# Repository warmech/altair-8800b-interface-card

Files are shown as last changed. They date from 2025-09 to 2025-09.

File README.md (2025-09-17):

# Altair 8800B Interface Card
This is a reproduction of the MITS Altair 8800B Interface card, with some cleanup to trace routing and pad placement and an additional quality of life improvement. This card serves as the interface between the Display/Control board and the rest of the 8800B.

This card originally used a staggered ribbon cable terminator that is both expensive and difficult to crimp unless you have the right tools. This version includes a set of two alternative 2x17, 0.1” headers to allow you to use a ribbon cable with female IDC on one end and card-edge on the other. If you cannot locate a pre-fabricated 34-pin cable with these terminators, inexpensive crimping tools are easily found at online retailers that will allow you to build your own cable. The original staggered terminator is crimped and soldered directly to the card PCB and this presented some issues. First, while these are available for sale at retailers such as Mouser and DigiKey, they are around $5.00 per connector (whereas nice, keyed male IDC connectors can be had for a fraction of that), they are not usually stocked in large quantities and may be back-ordered by the time you are assembling this card. Second, these staggered connectors have no stress relief and flexing/bending of the ribbon cables over time will cause the connector to loosen to the extent that signal transmission issues may arise between the interface card and the D/C board. In the case of my and others’ Altairs, this issue caused bus issues that were extremely difficult to hunt down and resolve. Last, if you are assembling your own cables, the staggered connectors require a special insert to crimp; these inserts are neither easy to find nor cheap, so an alternative IDC header offers an inexpensive alternative.

This design is presently untested and I am awaiting a set to be fabricated. Once I have tested this adapter in my 8800B, I will update this disclaimer to indicate as much. Until this disclaimer is updated and/or removed, this PCB is to be strictly treated as experimental only. User beware – these project and fabrication files are provided with absolutely zero guarantees.

For the accompanying CPU, Interface, and Display/Control boards, please see the following repositories:

[Altair 8800B CPU Card](https://github.com/warmech/altair-8800b-cpu-card)

[Altair 8800B Display/Control PCB](https://github.com/warmech/altair-8800b-display-control-pcb)

[Altair 8800B 1702-to-2716/2732 Adapter](https://github.com/warmech/altair-8800b-1702-to-2716-eprom-adapter)

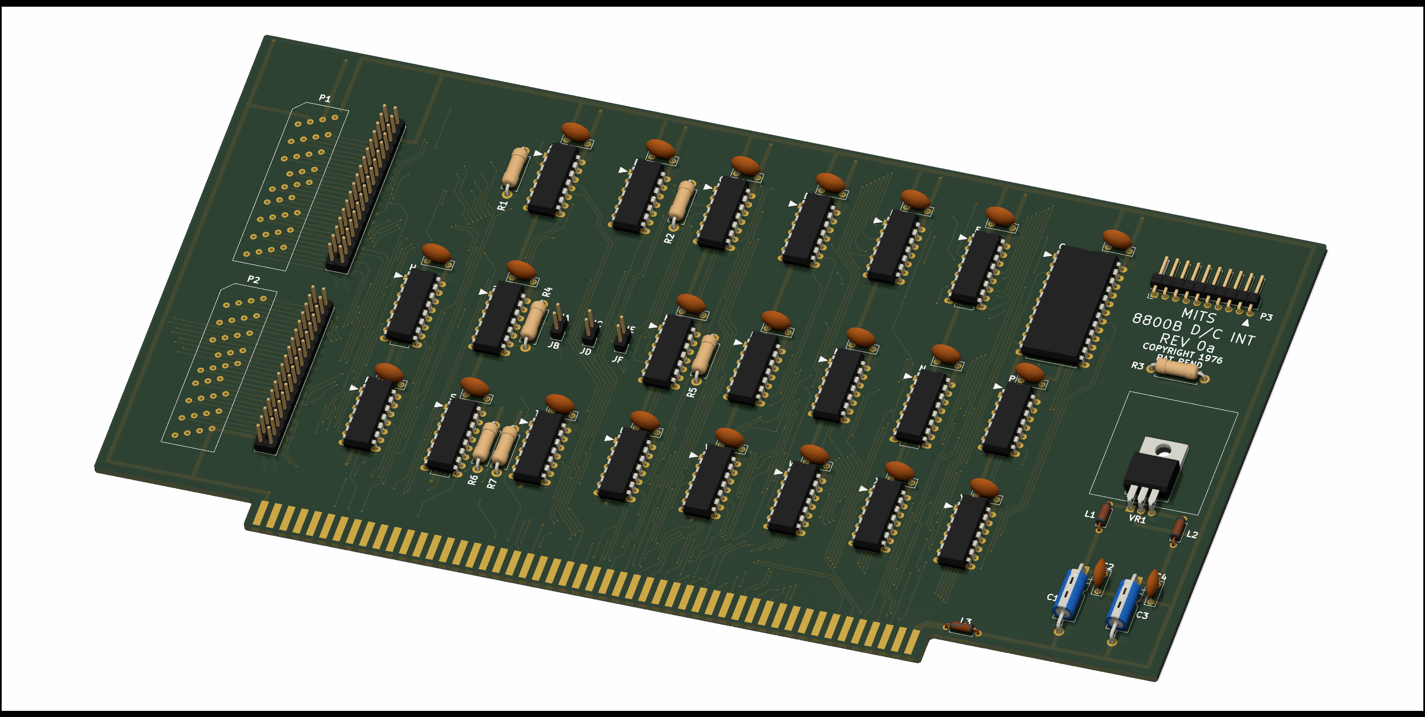
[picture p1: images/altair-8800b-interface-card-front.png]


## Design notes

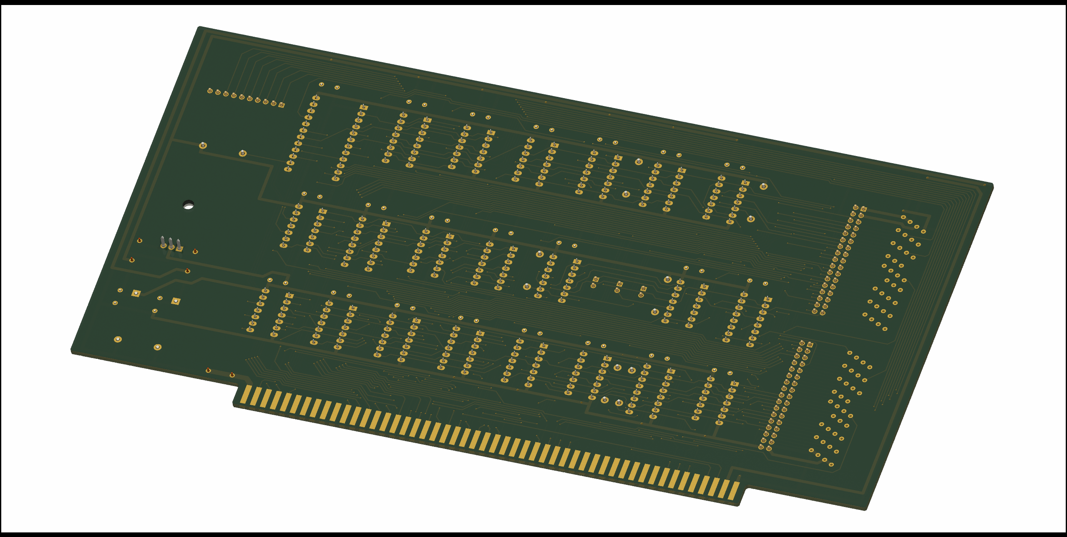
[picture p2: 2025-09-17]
images/altair-8800b-interface-card-rear.png

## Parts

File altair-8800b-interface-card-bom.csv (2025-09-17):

Source:
Date: | 9/17/2025 0:42
Tool: | Eeschema 7.0.11-rc3
Generator:
Component Count: | 68
Collated Components:
Item | Qty | Reference(s) | Value | LibPart | Footprint | Datasheet | DNP
1 | 2 | C1, C3 | 33uF / 16V | Device:C_Polarized_US | Capacitor_THT:CP_Axial_L11.0mm_D5.0mm_P18.00mm_Horizontal | ~
2 | 2 | C2, C4 | 0.1uF / 16V | Device:C | Capacitor_THT_Custom:C_Disc_D7.0mm_W2.3mm_P5.00mm | ~
3 | 22 | C5, C6, C7, C8, C9, C10, C11, C12, C13, C14, C15, C16, C17, C18, C19, C20, C21, C22, C23, C24, C25, C26 | 0.1uF / 12V | Device:C | Capacitor_THT_Custom:C_Disc_D7.0mm_W2.3mm_P5.00mm | ~
4 | 1 | JP1 | JA-JB | Jumper:Jumper_2_Open | Connector_PinHeader_2.54mm:PinHeader_1x02_P2.54mm_Vertical | ~
5 | 1 | JP2 | JC-JD | Jumper:Jumper_2_Open | Connector_PinHeader_2.54mm:PinHeader_1x02_P2.54mm_Vertical | ~
6 | 1 | JP3 | JE-JF | Jumper:Jumper_2_Open | Connector_PinHeader_2.54mm:PinHeader_1x02_P2.54mm_Vertical | ~
7 | 3 | L1, L2, L3 | L | Device:L | Inductor_THT:L_Axial_L5.3mm_D2.2mm_P7.62mm_Horizontal_Vishay_IM-1 | ~
8 | 2 | P1, P2 | ~ | Connector_Custom:Ribbon_Cable_Header_PCB_Connector_34_Pin | Connector_Custom:Ribbon_Cable_Header_PCB_Connector_34_Pin
9 | 1 | P3 | CPU Data Bus Conn | Connector_Generic:Conn_01x10 | Connector_PinHeader_2.54mm:PinHeader_1x10_P2.54mm_Horizontal | ~
10 | 1 | P4 | Altair System Bus (S-100) | Connector_Custom:MITS_Altair_Bus_CardEdge | Connector_Custom:Altair_8800_Bus_Card_Edge
11 | 2 | P5, P6 | Conn_02x17_Top_Bottom | Connector_Generic:Conn_02x17_Top_Bottom | Connector_PinHeader_2.54mm:PinHeader_2x17_P2.54mm_Vertical | ~
12 | 7 | R1, R2, R3, R4, R5, R6, R7 | 2.2K | Device:R_US | Resistor_THT:R_Axial_DIN0411_L9.9mm_D3.6mm_P12.70mm_Horizontal | ~
13 | 1 | U1 | 74LS13 (A) | 74xx:74LS13 | Package_DIP:DIP-14_W7.62mm_LongPads | http://www.ti.com/lit/gpn/sn74LS13
14 | 1 | U2 | 74LS13 (B) | 74xx:74LS13 | Package_DIP:DIP-14_W7.62mm_LongPads | http://www.ti.com/lit/gpn/sn74LS13
15 | 1 | U3 | 74LS04 (C) | 74xx:74LS04 | Package_DIP:DIP-14_W7.62mm_LongPads | http://www.ti.com/lit/gpn/sn74LS04
16 | 1 | U4 | 74LS02 (D) | 74xx:7402 | Package_DIP:DIP-14_W7.62mm_LongPads | http://www.ti.com/lit/gpn/sn7402
17 | 1 | U5 | 74LS04 (E) | 74xx:74LS04 | Package_DIP:DIP-14_W7.62mm_LongPads | http://www.ti.com/lit/gpn/sn74LS04
18 | 1 | U6 | 74LS367 (F) | :74LS367_6 | Package_DIP:DIP-16_W7.62mm_LongPads
19 | 1 | U7 | 8212 (G) | Interface_Custom:8212 | Package_DIP:DIP-24_W15.24mm_LongPads
20 | 1 | U8 | 74LS367 (H) | :74LS367_8 | Package_DIP:DIP-16_W7.62mm_LongPads
21 | 1 | U9 | 74LS00 (J) | 74xx:7400 | Package_DIP:DIP-14_W7.62mm_LongPads | http://www.ti.com/lit/gpn/sn7400
22 | 1 | U10 | 74LS10 (K) | 74xx:74LS10 | Package_DIP:DIP-14_W7.62mm_LongPads | http://www.ti.com/lit/gpn/sn74LS10
23 | 1 | U11 | 74LS13 (L) | 74xx:74LS13 | Package_DIP:DIP-14_W7.62mm_LongPads | http://www.ti.com/lit/gpn/sn74LS13
24 | 1 | U12 | 74LS04 (M) | 74xx:74LS04 | Package_DIP:DIP-14_W7.62mm_LongPads | http://www.ti.com/lit/gpn/sn74LS04
25 | 1 | U13 | 74LS367 (N) | :74LS367_20 | Package_DIP:DIP-16_W7.62mm_LongPads
26 | 1 | U14 | 74LS04 (P) | 74xx:74LS04 | Package_DIP:DIP-14_W7.62mm_LongPads | http://www.ti.com/lit/gpn/sn74LS04
27 | 1 | U16 | 74LS04 (R) | 74xx:74LS04 | Package_DIP:DIP-14_W7.62mm_LongPads | http://www.ti.com/lit/gpn/sn74LS04
28 | 1 | U17 | 74LS367 (S) | :74LS367_26 | Package_DIP:DIP-16_W7.62mm_LongPads
29 | 1 | U18 | 74LS04 (T) | 74xx:74LS04 | Package_DIP:DIP-14_W7.62mm_LongPads | http://www.ti.com/lit/gpn/sn74LS04
30 | 1 | U19 | 74LS04 (U) | 74xx:74LS04 | Package_DIP:DIP-14_W7.62mm_LongPads | http://www.ti.com/lit/gpn/sn74LS04
31 | 1 | U20 | 74LS04 (V) | 74xx:74LS04 | Package_DIP:DIP-14_W7.62mm_LongPads | http://www.ti.com/lit/gpn/sn74LS04
32 | 1 | U21 | 74LS04 (W) | 74xx:74LS04 | Package_DIP:DIP-14_W7.62mm_LongPads | http://www.ti.com/lit/gpn/sn74LS04
33 | 1 | U22 | 74LS04 (X) | 74xx:74LS04 | Package_DIP:DIP-14_W7.62mm_LongPads | http://www.ti.com/lit/gpn/sn74LS04
34 | 1 | U23 | 74LS04 (Y) | 74xx:74LS04 | Package_DIP:DIP-14_W7.62mm_LongPads | http://www.ti.com/lit/gpn/sn74LS04
35 | 1 | VR1 | 7805 | Regulator_Linear:L7805 | Package_TO_SOT_THT:TO-220-3_Horizontal_TabDown | http://www.st.com/content/ccc/resource/technical/document/datasheet/41/4f/b3/b0/12/d4/47/88/CD00000444.pdf/files/CD00000444.pdf/jcr:content/translations/en.CD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

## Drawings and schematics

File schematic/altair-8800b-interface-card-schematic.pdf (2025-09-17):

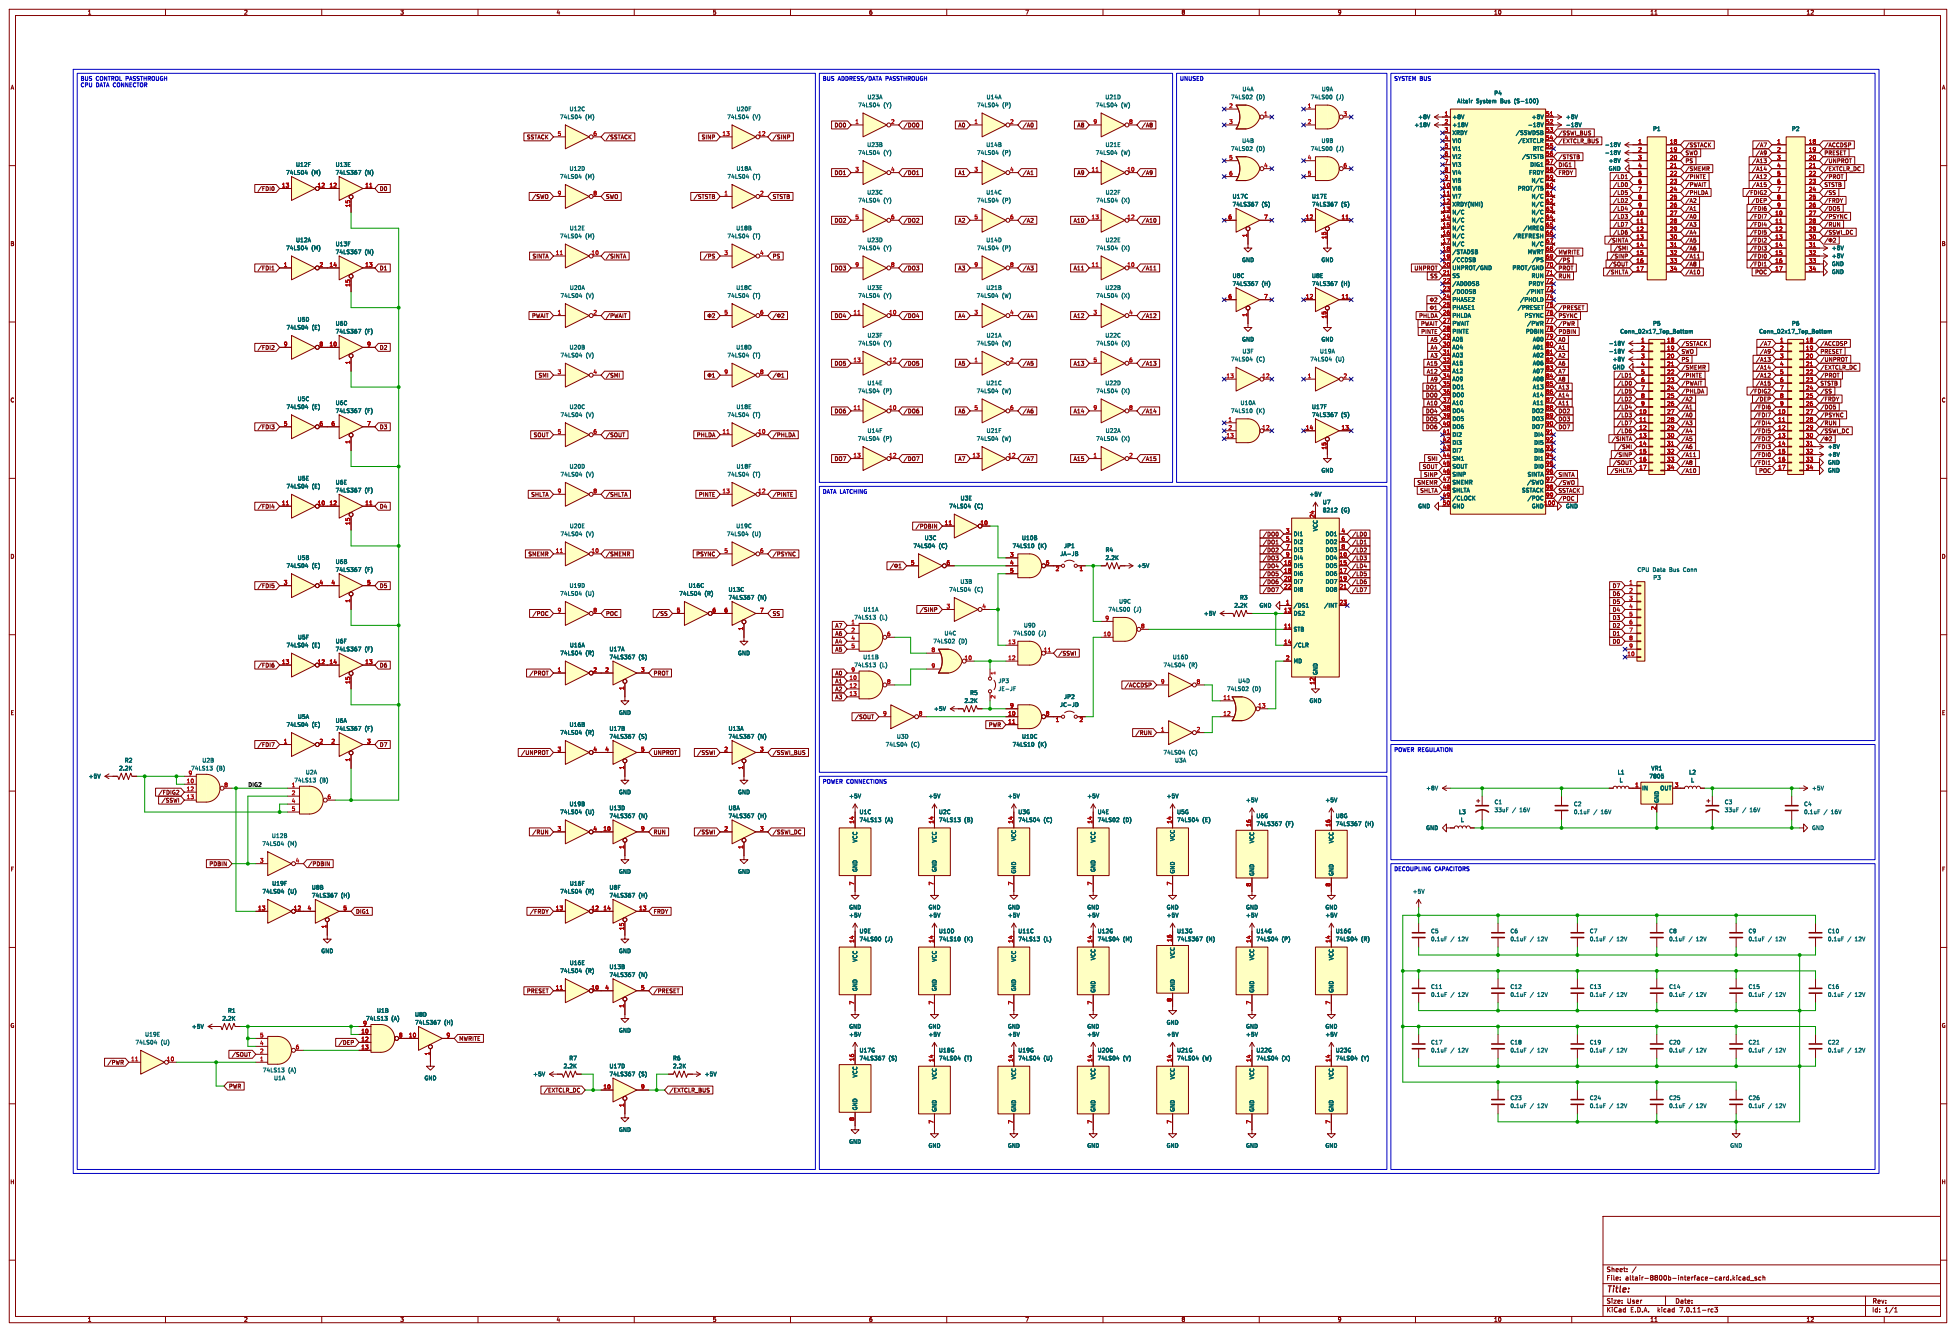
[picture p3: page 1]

74LS04 (W) GND GND GND GND

Id: 1/1 Title: File: altair-8800b-interface-card.kicad_sch Sheet: /

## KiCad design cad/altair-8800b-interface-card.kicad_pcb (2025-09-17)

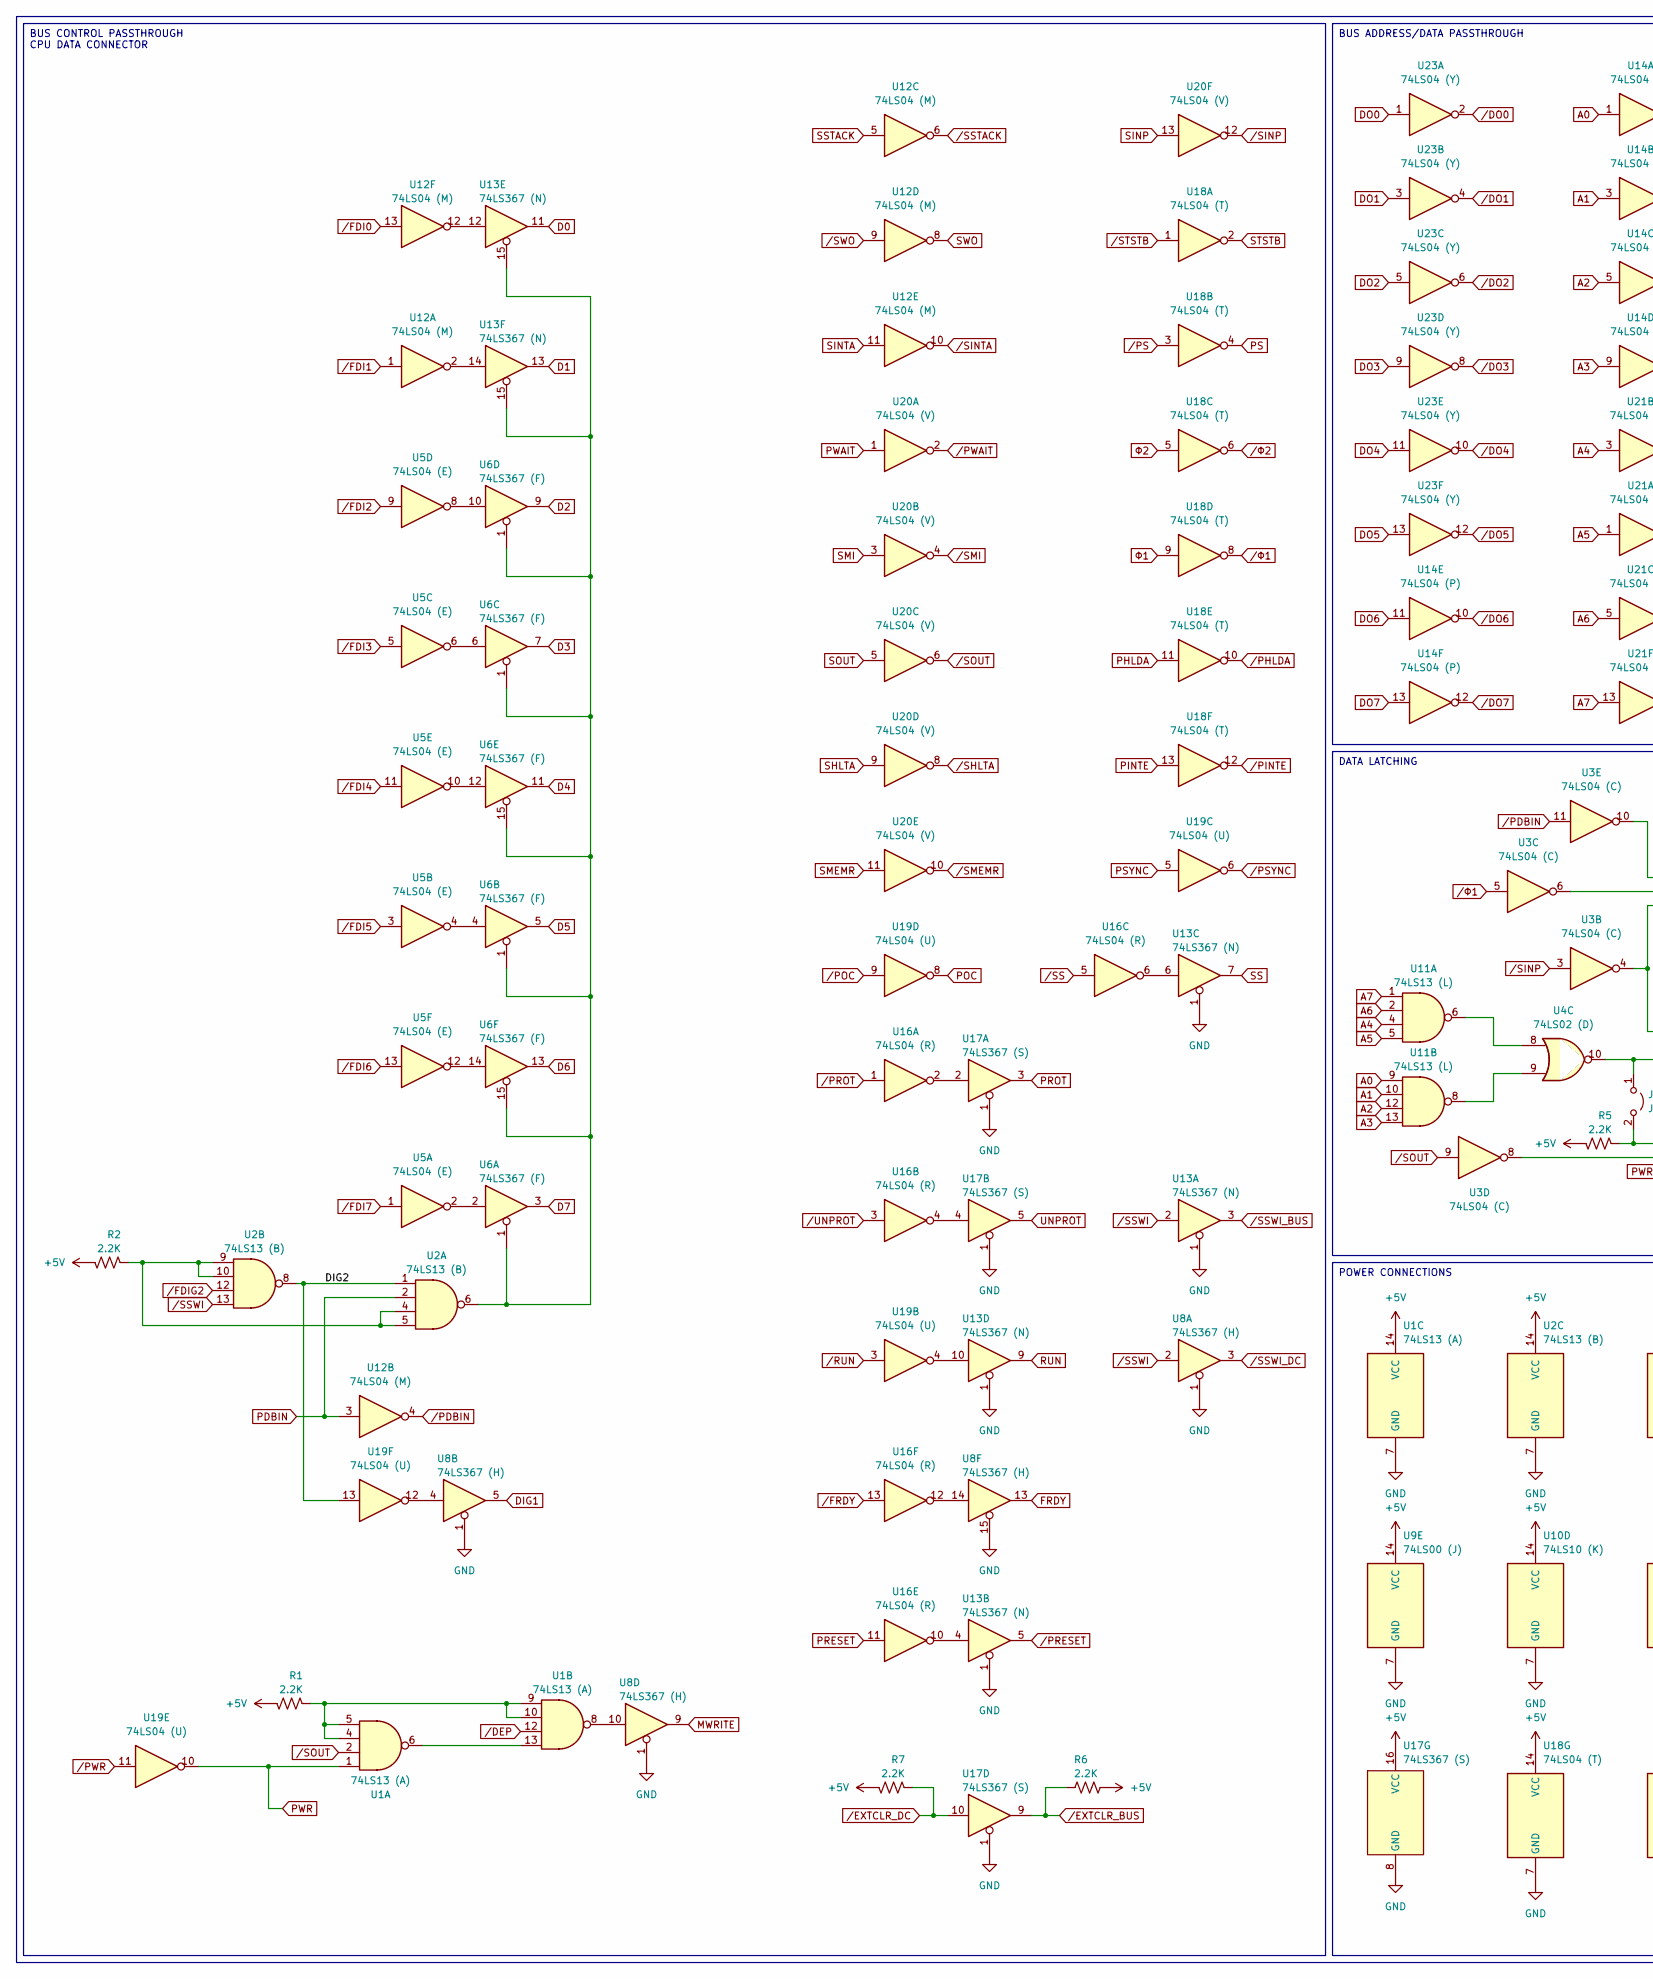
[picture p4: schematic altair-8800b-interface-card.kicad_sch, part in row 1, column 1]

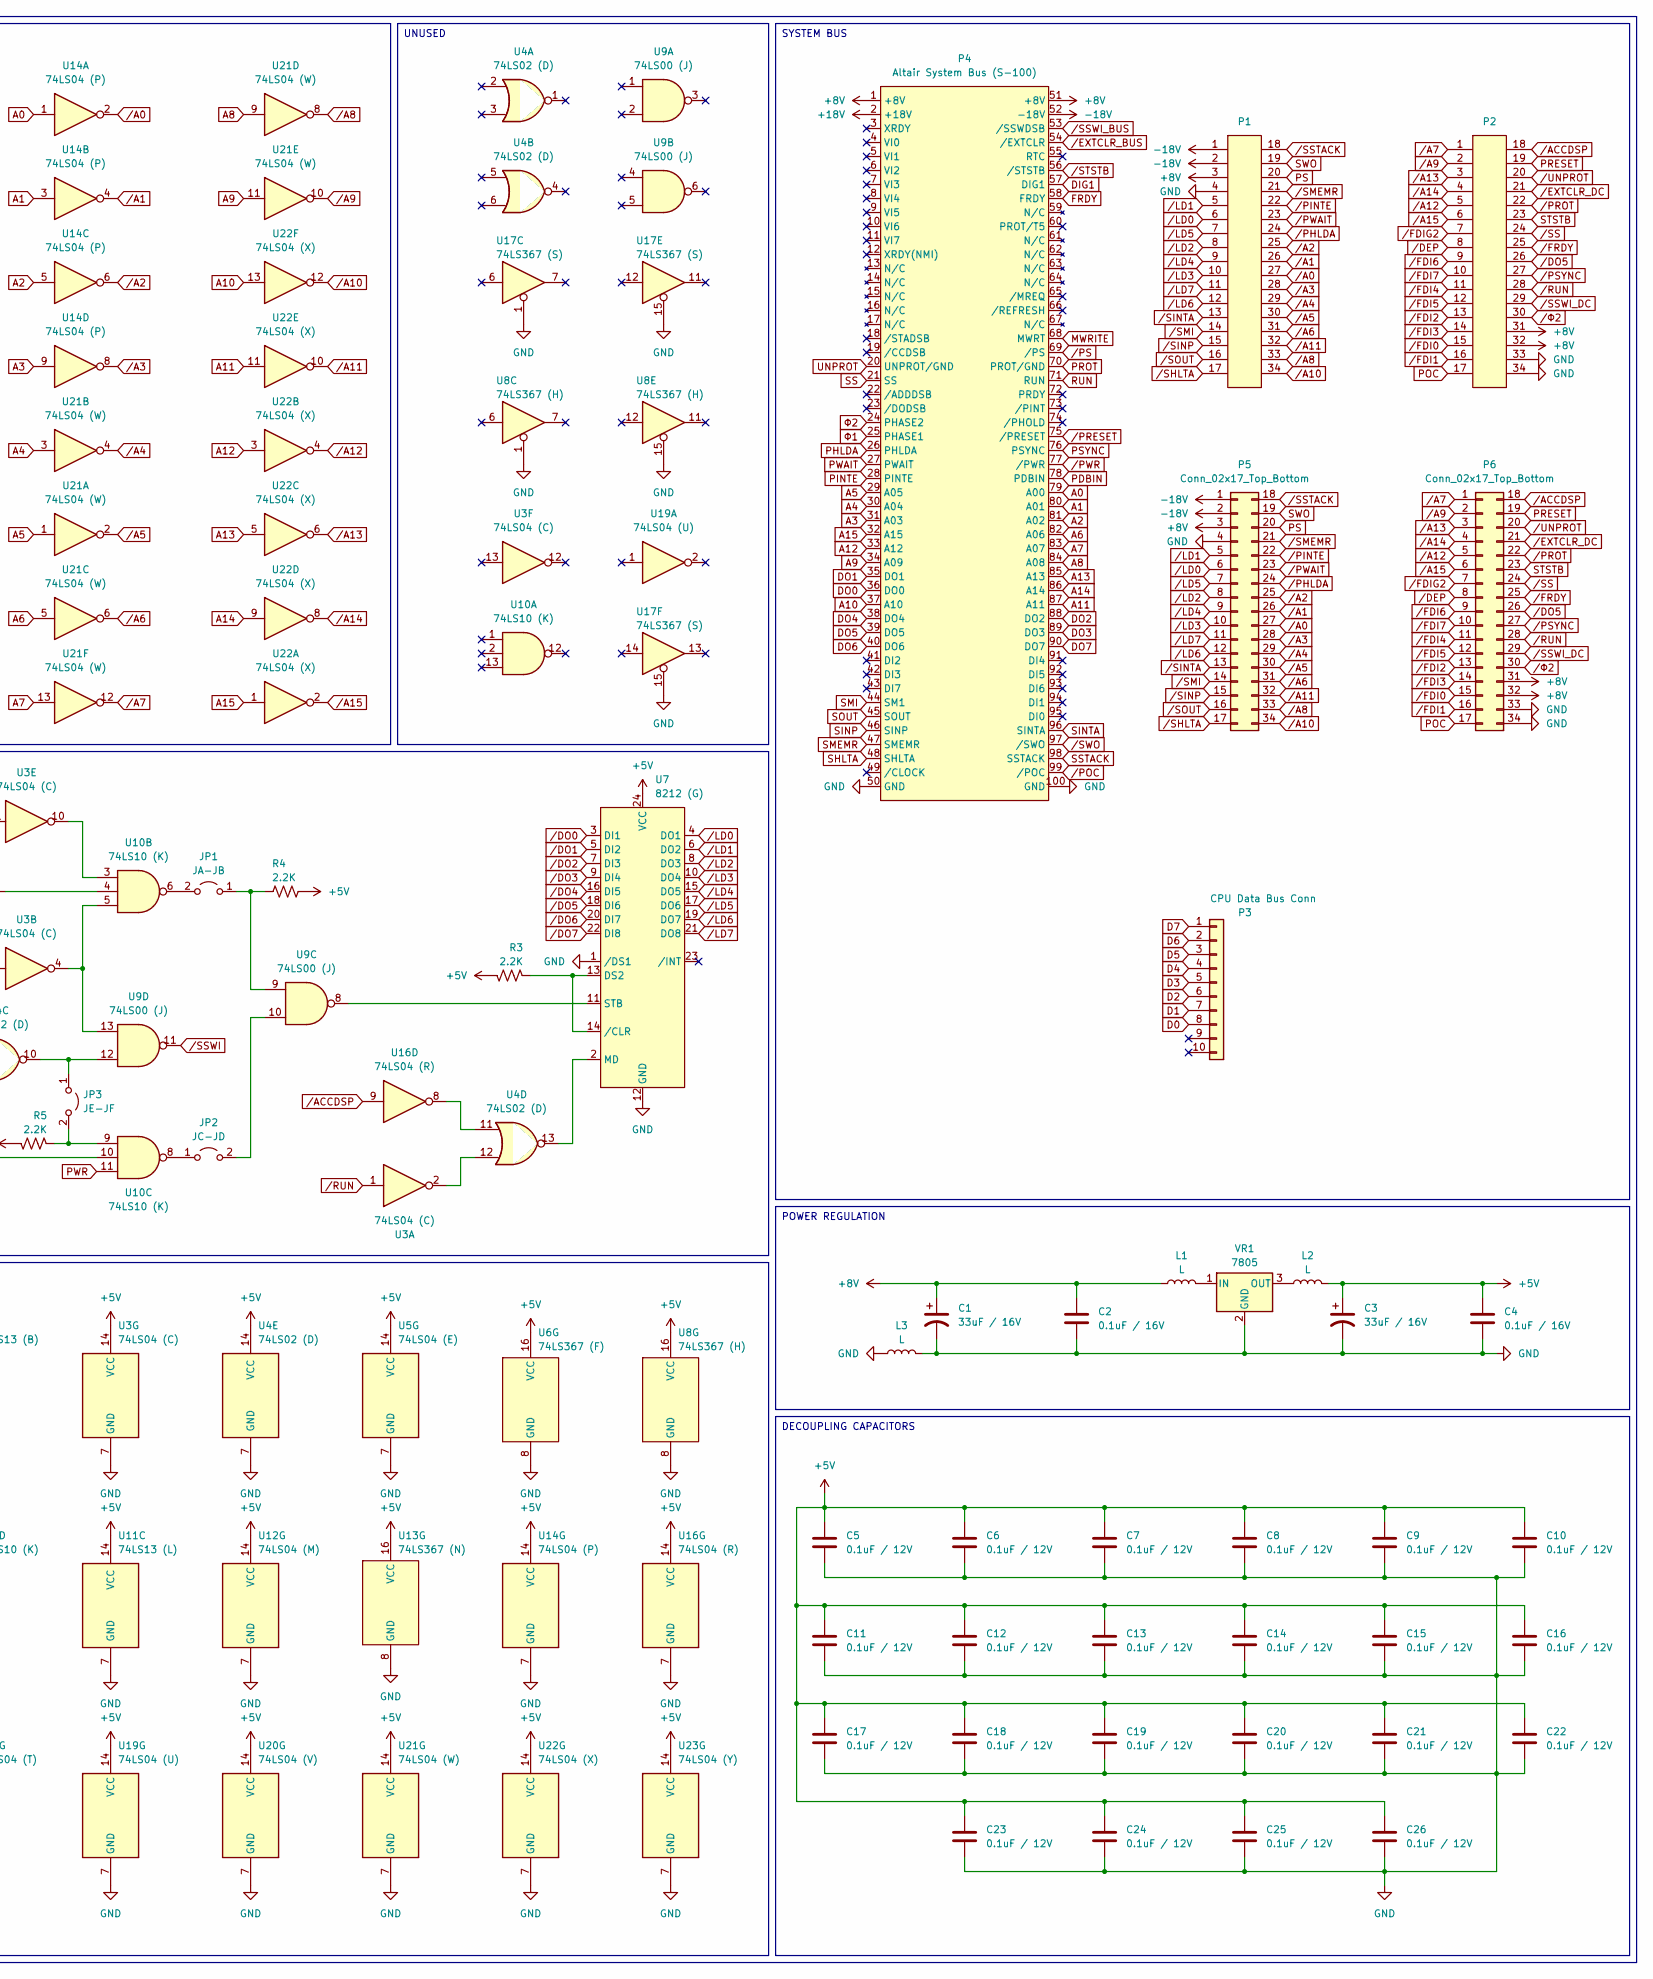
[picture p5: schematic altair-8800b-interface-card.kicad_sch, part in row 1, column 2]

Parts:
C1, C3: 33uF / 16V; CP_Axial_L11.0mm_D5.0mm_P18.00mm_Horizontal
C2, C4: 0.1uF / 16V; C_Disc_D7.0mm_W2.3mm_P5.00mm
C5, C6, C7, C8, C9, C10, C11, C12, C13, C14, C15, C16, C17, C18, C19, C20, C21, C22, C23, C24, C25, C26: 0.1uF / 12V; C_Disc_D7.0mm_W2.3mm_P5.00mm
JP1: JA-JB; PinHeader_1x02_P2.54mm_Vertical
JP2: JC-JD; PinHeader_1x02_P2.54mm_Vertical
JP3: JE-JF; PinHeader_1x02_P2.54mm_Vertical
L1, L2, L3: L; L_Axial_L5.3mm_D2.2mm_P7.62mm_Horizontal_Vishay_IM-1
P1, P2: Ribbon_Cable_Header_PCB_Connector_34_Pin
P3: CPU Data Bus Conn; PinHeader_1x10_P2.54mm_Horizontal
P4: Altair System Bus (S-100); Altair_8800_Bus_Card_Edge
P5, P6: Conn_02x17_Top_Bottom; PinHeader_2x17_P2.54mm_Vertical
R1, R2, R3, R4, R5, R6, R7: 2.2K; R_Axial_DIN0411_L9.9mm_D3.6mm_P12.70mm_Horizontal
U1: 74LS13 (A); DIP-14_W7.62mm_LongPads
U2: 74LS13 (B); DIP-14_W7.62mm_LongPads
U3: 74LS04 (C); DIP-14_W7.62mm_LongPads
U4: 74LS02 (D); DIP-14_W7.62mm_LongPads
U5: 74LS04 (E); DIP-14_W7.62mm_LongPads
U6: 74LS367 (F); DIP-16_W7.62mm_LongPads
U7: 8212 (G); DIP-24_W15.24mm_LongPads
U8: 74LS367 (H); DIP-16_W7.62mm_LongPads
U9: 74LS00 (J); DIP-14_W7.62mm_LongPads
U10: 74LS10 (K); DIP-14_W7.62mm_LongPads
U11: 74LS13 (L); DIP-14_W7.62mm_LongPads
U12: 74LS04 (M); DIP-14_W7.62mm_LongPads
U13: 74LS367 (N); DIP-16_W7.62mm_LongPads
U14: 74LS04 (P); DIP-14_W7.62mm_LongPads
U16: 74LS04 (R); DIP-14_W7.62mm_LongPads
U17: 74LS367 (S); DIP-16_W7.62mm_LongPads
U18: 74LS04 (T); DIP-14_W7.62mm_LongPads
U19: 74LS04 (U); DIP-14_W7.62mm_LongPads
U20: 74LS04 (V); DIP-14_W7.62mm_LongPads
U21: 74LS04 (W); DIP-14_W7.62mm_LongPads
U22: 74LS04 (X); DIP-14_W7.62mm_LongPads
U23: 74LS04 (Y); DIP-14_W7.62mm_LongPads
VR1: 7805; TO-220-3_Horizontal_TabDown

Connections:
+5V: C3.1, C4.1, C5.1, C6.1, C7.1, C8.1, C9.1, C10.1, C11.1, C12.1, C13.1, C14.1, C15.1, C16.1, C17.1, C18.1, C19.1, C20.1, C21.1, C22.1, C23.1, C24.1, C25.1, C26.1, L2.2, R1.1, R2.1, R3.1, R4.1, R5.1, R6.1, R7.1, U1.14 (VCC), U2.14 (VCC), U3.14 (VCC), U4.14 (VCC), U5.14 (VCC), U6.16 (VCC), U7.24 (VCC), U8.16 (VCC), U9.14 (VCC), U10.14 (VCC), U11.14 (VCC), U12.14 (VCC), U13.16 (VCC), U14.14 (VCC), U16.14 (VCC), U17.16 (VCC), U18.14 (VCC), U19.14 (VCC), U20.14 (VCC), U21.14 (VCC), U22.14 (VCC), U23.14 (VCC)
+8V: C1.1, C2.1, L1.1, P1.3, P2.31, P2.32, P4.1 (+8V), P4.51 (+8V), P5.3, P6.31, P6.32
+18V: P4.2 (+18V)
-18V: P1.1, P1.2, P4.52 (-18V), P5.1, P5.2
/DIG2: U2.1, U2.8, U19.13
A0: P4.79 (A00), U11.9, U14.1
A1: P4.80 (A01), U11.10, U14.3
A2: P4.81 (A02), U11.12, U14.5
A3: P4.31 (A03), U11.13, U14.9
A4: P4.30 (A04), U11.4, U21.3
A5: P4.29 (A05), U11.5, U21.1
A6: P4.82 (A06), U11.2, U21.5
A7: P4.83 (A07), U11.1, U21.13
A8: P4.84 (A08), U21.9
A9: P4.34 (A09), U21.11
A10: P4.37 (A10), U22.13
A11: P4.87 (A11), U22.11
A12: P4.33 (A12), U22.3
A13: P4.85 (A13), U22.5
A14: P4.86 (A14), U22.9
A15: P4.32 (A15), U22.1
D0: P3.8, U13.11
D1: P3.7, U13.13
D2: P3.6, U6.9
D3: P3.5, U6.7
D4: P3.4, U6.11
D5: P3.3, U6.5
D6: P3.2, U6.13
D7: P3.1, U6.3
DIG1: P4.57 (DIG1), U8.5
DO0: P4.36 (DO0), U23.1
DO1: P4.35 (DO1), U23.3
DO2: P4.88 (DO2), U23.5
DO3: P4.89 (DO3), U23.9
DO4: P4.38 (DO4), U23.11
DO5: P4.39 (DO5), U23.13
DO6: P4.40 (DO6), U14.11
DO7: P4.90 (DO7), U14.13
FRDY: P4.58 (FRDY), U8.13
GND: C1.2, C2.2, C3.2, C4.2, C5.2, C6.2, C7.2, C8.2, C9.2, C10.2, C11.2, C12.2, C13.2, C14.2, C15.2, C16.2, C17.2, C18.2, C19.2, C20.2, C21.2, C22.2, C23.2, C24.2, C25.2, C26.2, L3.1, L3.2, P1.4, P2.33, P2.34, P4.50 (GND), P4.100 (GND), P5.4, P6.33, P6.34, U1.7 (GND), U2.7 (GND), U3.7 (GND), U4.7 (GND), U5.7 (GND), U6.8 (GND), U7.1 (/DS1), U7.12 (GND), U8.1, U8.8 (GND), U8.15, U9.7 (GND), U10.7 (GND), U11.7 (GND), U12.7 (GND), U13.1, U13.8 (GND), U14.7 (GND), U16.7 (GND), U17.1, U17.8 (GND), U17.15, U18.7 (GND), U19.7 (GND), U20.7 (GND), U21.7 (GND), U22.7 (GND), U23.7 (GND), VR1.2 (GND)
MWRITE: P4.68 (MWRT), U8.9
unnamed: JP1.1 (A), R4.2, U9.9
unnamed: JP1.2 (B), U10.6
unnamed: JP2.1 (A), U10.8
unnamed: JP2.2 (B), U9.10
unnamed: JP3.1 (A), U4.10, U9.12
unnamed: JP3.2 (B), R5.2, U10.9
unnamed: R1.2, U1.4, U1.5, U1.9, U1.10
unnamed: R2.2, U2.4, U2.5, U2.9, U2.10
unnamed: U1.8, U8.10
unnamed: U1.6, U1.13
unnamed: U3.2, U4.12
unnamed: U5.2, U6.2
unnamed: U5.4, U6.4
unnamed: U5.6, U6.6
unnamed: U5.8, U6.10
unnamed: U5.10, U6.12
unnamed: U5.12, U6.14
unnamed: R3.2, U7.13 (DS2), U7.14 (/CLR)
unnamed: U4.13, U7.2 (MD)
unnamed: U7.11 (STB), U9.8
unnamed: U3.10, U10.3
unnamed: U3.6, U10.4
unnamed: U3.4, U9.13, U10.5
unnamed: U3.8, U10.10
unnamed: U4.8, U11.6
unnamed: U4.9, U11.8
unnamed: U12.2, U13.14
unnamed: U12.12, U13.12
unnamed: U13.4, U16.10
unnamed: U13.6, U16.6
unnamed: U13.10, U19.4
unnamed: U2.6, U6.1, U6.15, U13.15
unnamed: U16.2, U17.2
unnamed: U16.4, U17.4
unnamed: U4.11, U16.8
unnamed: U8.14, U16.12
unnamed: U8.4, U19.12
unnamed: L1.2, VR1.1 (IN)
unnamed: L2.1, VR1.3 (OUT)
PDBIN: P4.78 (PDBIN), U2.2, U12.3
PHLDA: P4.26 (PHLDA), U18.11
PINTE: P4.28 (PINTE), U18.13
POC: P2.17, P6.17, U19.8
PRESET: P2.19, P6.19, U16.11
PROT: P4.70 (PROT/GND), U17.3
PS: P1.20, P5.20, U18.4
PSYNC: P4.76 (PSYNC), U19.5
PWAIT: P4.27 (PWAIT), U20.1
PWR: U1.1, U10.11, U19.10
RUN: P4.71 (RUN), U13.9
SHLTA: P4.48 (SHLTA), U20.9
SINP: P4.46 (SINP), U20.13
SINTA: P4.96 (SINTA), U12.11
SMEMR: P4.47 (SMEMR), U20.11
SMI: P4.44 (SM1), U20.3
SOUT: P4.45 (SOUT), U20.5
SS: P4.21 (SS), U13.7
SSTACK: P4.98 (SSTACK), U12.5
STSTB: P2.23, P6.23, U18.2
SWO: P1.19, P5.19, U12.8
UNPROT: P4.20 (UNPROT/GND), U17.5
/A0: P1.27, P5.27, U14.2
/A1: P1.26, P5.26, U14.4
/A2: P1.25, P5.25, U14.6
/A3: P1.28, P5.28, U14.8
/A4: P1.29, P5.29, U21.4
/A5: P1.30, P5.30, U21.2
/A6: P1.31, P5.31, U21.6
/A7: P2.1, P6.1, U21.12
/A8: P1.33, P5.33, U21.8
/A9: P2.2, P6.2, U21.10
/A10: P1.34, P5.34, U22.12
/A11: P1.32, P5.32, U22.10
/A12: P2.5, P6.5, U22.4
/A13: P2.3, P6.3, U22.6
/A14: P2.4, P6.4, U22.8
/A15: P2.6, P6.6, U22.2
/ACCDSP: P2.18, P6.18, U16.9
/DEP: P2.8, P6.8, U1.12
/DO0: U7.3 (DI1), U23.2
/DO1: U7.5 (DI2), U23.4
/DO2: U7.7 (DI3), U23.6
/DO3: U7.9 (DI4), U23.8
/DO4: U7.16 (DI5), U23.10
/DO5: P2.26, P6.26, U7.18 (DI6), U23.12
/DO6: U7.20 (DI7), U14.10
/DO7: U7.22 (DI8), U14.12
/EXTCLR_BUS: P4.54 (/EXTCLR), R6.2, U17.9
/EXTCLR_DC: P2.21, P6.21, R7.2, U17.10
/FDI0: P2.15, P6.15, U12.13
/FDI1: P2.16, P6.16, U12.1
/FDI2: P2.13, P6.13, U5.9
/FDI3: P2.14, P6.14, U5.5
/FDI4: P2.11, P6.11, U5.11
/FDI5: P2.12, P6.12, U5.3
/FDI6: P2.9, P6.9, U5.13
/FDI7: P2.10, P6.10, U5.1
/FDIG2: P2.7, P6.7, U2.12
/FRDY: P2.25, P6.25, U16.13
/LD0: P1.6, P5.6, U7.4 (DO1)
/LD1: P1.5, P5.5, U7.6 (DO2)
/LD2: P1.8, P5.8, U7.8 (DO3)
/LD3: P1.10, P5.10, U7.10 (DO4)
/LD4: P1.9, P5.9, U7.15 (DO5)
/LD5: P1.7, P5.7, U7.17 (DO6)
/LD6: P1.12, P5.12, U7.19 (DO7)
/LD7: P1.11, P5.11, U7.21 (DO8)
/PDBIN: U3.11, U12.4
/PHLDA: P1.24, P5.24, U18.10
/PINTE: P1.22, P5.22, U18.12
/POC: P4.99 (/POC), U19.9
/PRESET: P4.75 (/PRESET), U13.5
/PROT: P2.22, P6.22, U16.1
/PS: P4.69 (/PS), U18.3
/PSYNC: P2.27, P6.27, U19.6
/PWAIT: P1.23, P5.23, U20.2
/PWR: P4.77 (/PWR), U19.11
/RUN: P2.28, P6.28, U3.1, U19.3
/SHLTA: P1.17, P5.17, U20.8
/SINP: P1.15, P5.15, U3.3, U20.12
/SINTA: P1.13, P5.13, U12.10
/SMEMR: P1.21, P5.21, U20.10
/SMI: P1.14, P5.14, U20.4
/SOUT: P1.16, P5.16, U1.2, U3.9, U20.6
/SS: P2.24, P6.24, U16.5
/SSTACK: P1.18, P5.18, U12.6
/SSWI: U2.13, U8.2, U9.11, U13.2
/SSWI_BUS: P4.53 (/SSWDSB), U13.3
/SSWI_DC: P2.29, P6.29, U8.3
/STSTB: P4.56 (/STSTB), U18.1
/SWO: P4.97 (/SWO), U12.9
/UNPROT: P2.20, P6.20, U16.3
/Φ1: U3.5, U18.8
/Φ2: P2.30, P6.30, U18.6
Φ1: P4.25 (PHASE1), U18.9
Φ2: P4.24 (PHASE2), U18.5

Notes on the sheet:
SYSTEM BUS
BUS CONTROL PASSTHROUGH CPU DATA CONNECTOR
DATA LATCHING
POWER REGULATION
POWER CONNECTIONS
UNUSED
DECOUPLING CAPACITORS
BUS ADDRESS/DATA PASSTHROUGH

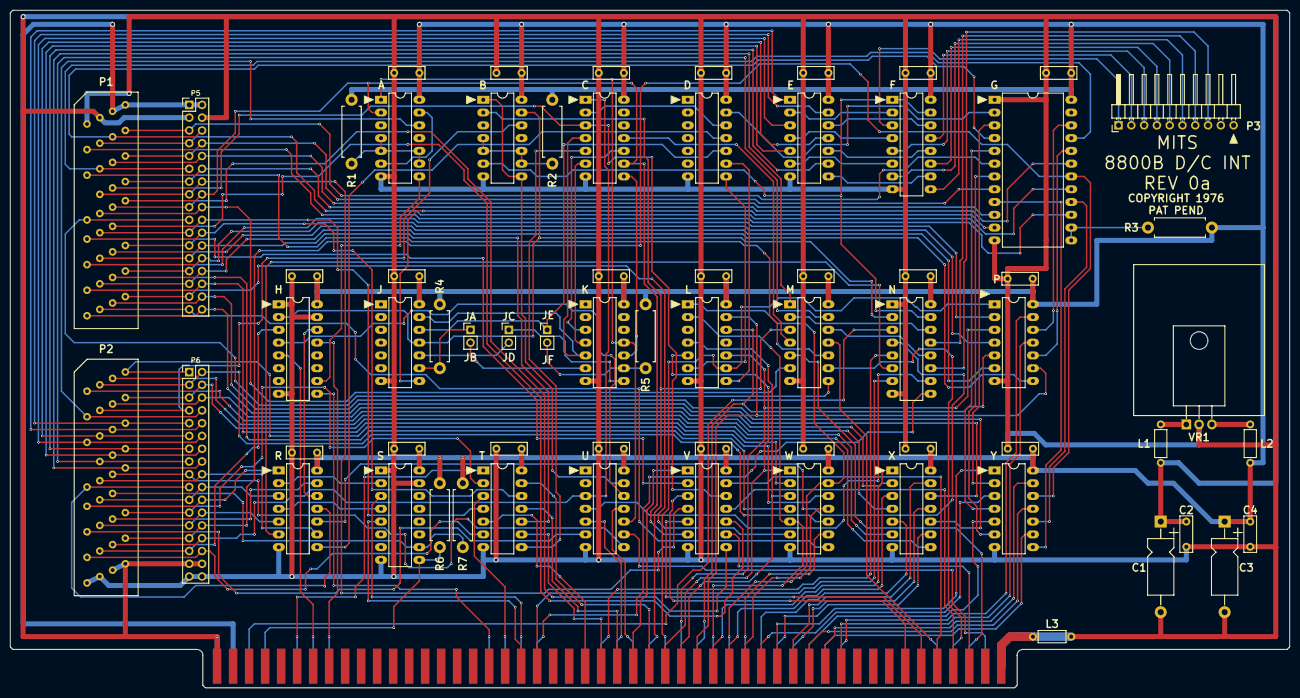
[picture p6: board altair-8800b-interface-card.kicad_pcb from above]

Board: 2 copper layers, 254.2 x 134.6 mm, 68 parts (0 on the bottom side), 176 nets.

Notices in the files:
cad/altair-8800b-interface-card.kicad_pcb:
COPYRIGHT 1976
